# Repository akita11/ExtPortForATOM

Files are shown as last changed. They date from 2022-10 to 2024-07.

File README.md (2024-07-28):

# ExtPortForATOM

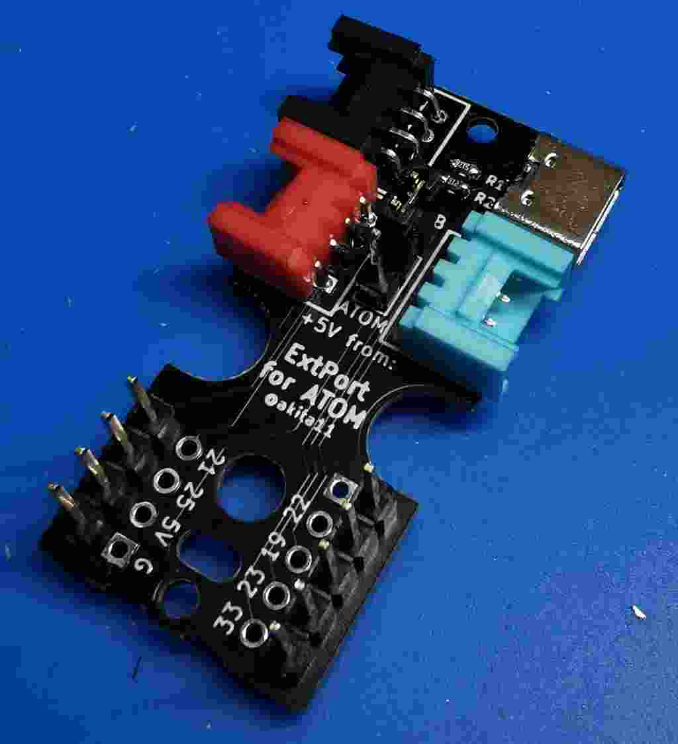
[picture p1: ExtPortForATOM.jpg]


M5stackのATOMシリーズ ([Lite](https://www.switch-science.com/products/6262) / [Matrix](https://www.switch-science.com/products/6260)に3つのGroveポートを拡張します。Groveポートへの給電はATOMから、またはUSB Type-Cコネクタからを選択できます。

※M5Stack純正の[ATOM PortABC](https://www.switch-science.com/products/9198)とピン配置・コネクタの色は同一ですが、Portの名称が異なります(本品=B/C/D、ATOM PortABC=A/B/C)

## 使い方

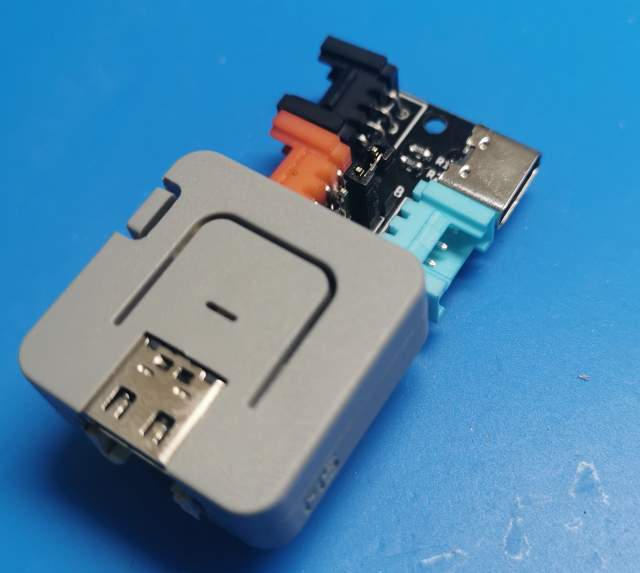
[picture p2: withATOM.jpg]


ATOMを上図のように取り付けて使います。

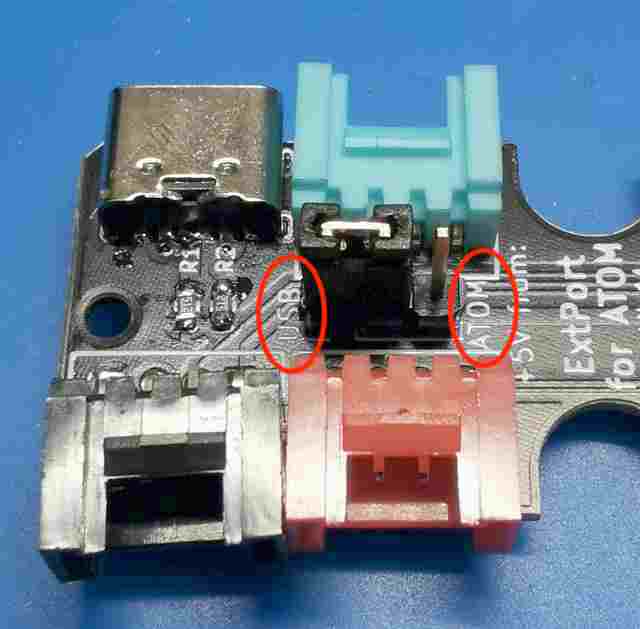
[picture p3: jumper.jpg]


GroveポートのVDD(+5V)への給電は、ボード上のショートピンで切り替えることができます。

- ”ATOM"側 : ATOMの+5V端子から給電（デフォルト）
- ”USB"側 : USB Type-C端子から給電（別途、USB ACアダプタやモバイルバッテリ等から給電してください）

## ピン配置

各ポートはATOMの以下のIOピンに接続されています。UIFlowからも利用可能となる予定です。

- PortB（赤色） : IO21/IO25/VDD/GND
- PortC（黒色） : IO33/IO23/VDD/GND
- PortD（青色） : IO19/IO22/VDD/GND

※ATOM-S3の場合は以下のようになります。

- PortB（赤色） : IO39/IO38/VDD/GND
- PortC（黒色） : IO8/IO7/VDD/GND
- PortD（青色） : IO6/IO5/VDD/GND

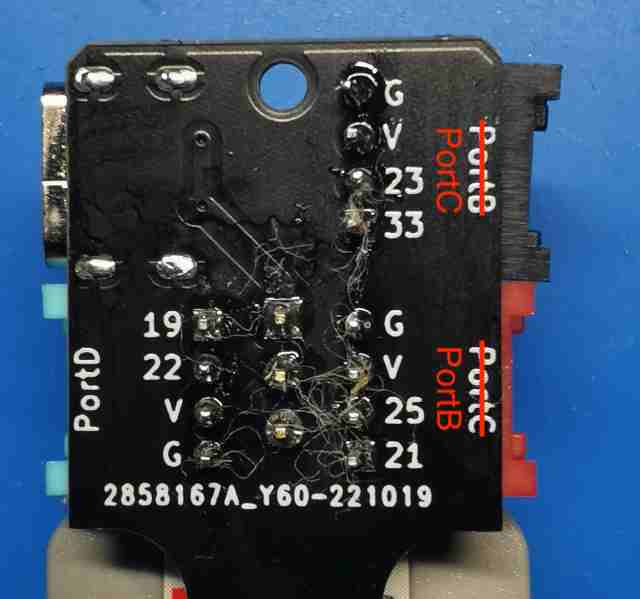
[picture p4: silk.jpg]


※初期ロットでは裏面シルクに間違いがあります。PortBとPortCの表記が逆になっていますのでご注意ください。（コネクタの色で各Portの名称を確認してください）

## Author

Junichi Akita (akita@ifdl.jp, @akita11)

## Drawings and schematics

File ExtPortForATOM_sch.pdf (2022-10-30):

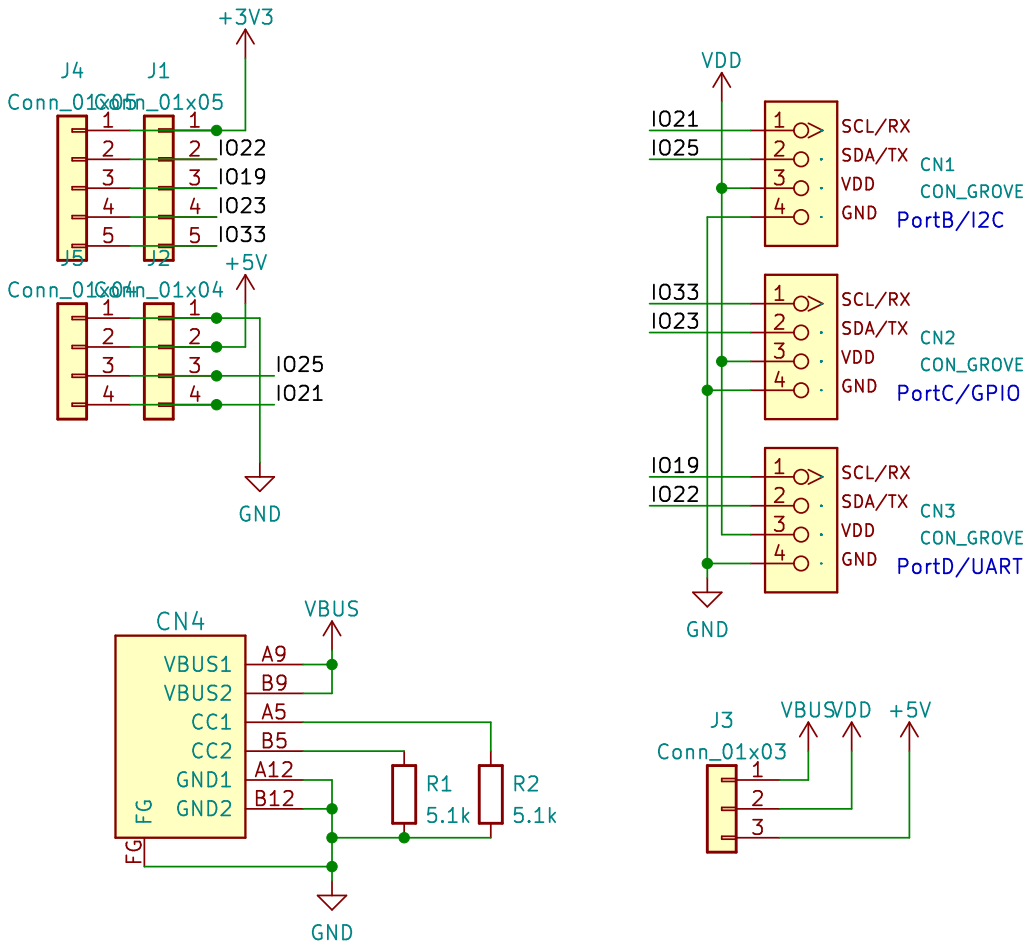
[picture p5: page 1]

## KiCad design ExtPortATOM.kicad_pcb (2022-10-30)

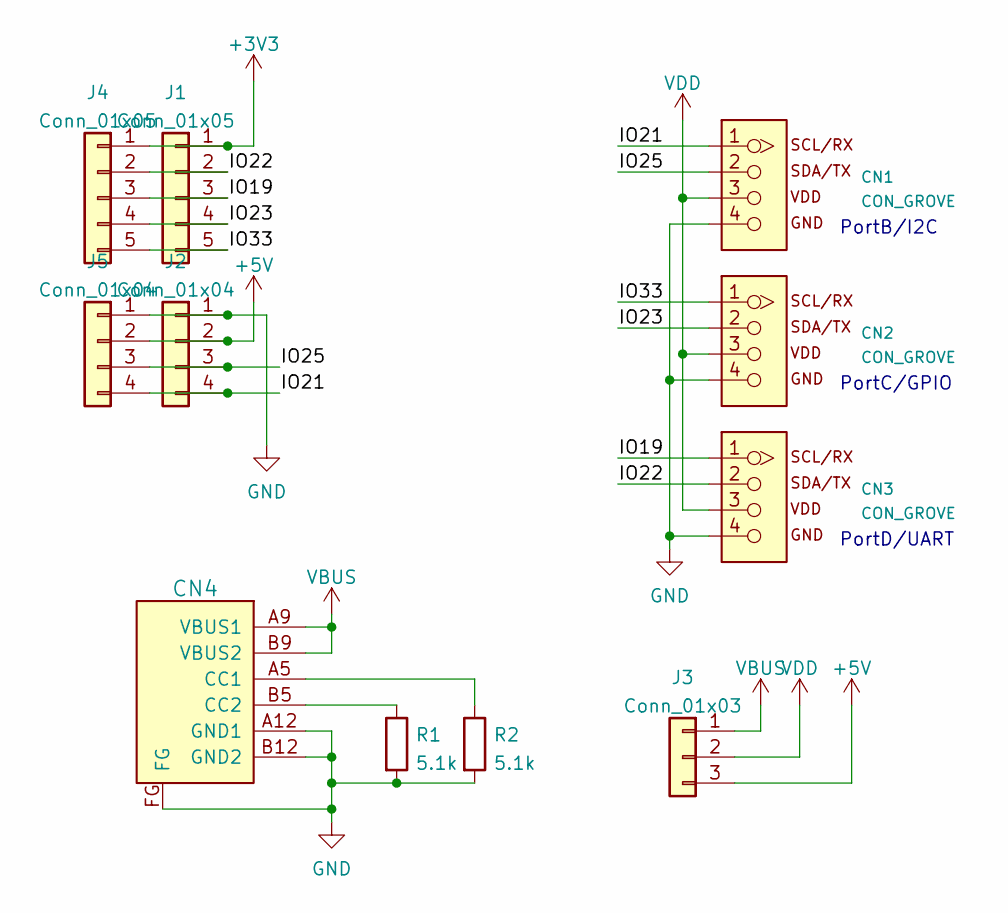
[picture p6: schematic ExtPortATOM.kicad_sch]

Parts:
CN1, CN2, CN3: CON_GROVE; CON_GROVE_H
CN4: CON_USB-C-6; USB-C_6P
J1, J4: Conn_01x05; PinHeader_1x05_P2.54mm_Vertical
J2, J5: Conn_01x04; PinHeader_1x04_P2.54mm_Vertical
J3: Conn_01x03; PinHeader_1x03_P2.54mm_Vertical
R1, R2: 5.1k; R_0603_1608Metric

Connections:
+3V3: J1.1, J4.1
+5V: J2.2, J3.3, J5.2
/IO19: CN3.1, J1.3, J4.3
/IO21: CN1.1, J2.4, J5.4
/IO22: CN3.2, J1.2, J4.2
/IO23: CN2.2, J1.4, J4.4
/IO25: CN1.2, J2.3, J5.3
/IO33: CN2.1, J1.5, J4.5
GND: CN1.4, CN2.4, CN3.4, CN4.A12 (GND1), CN4.B12 (GND2), CN4.FG, J2.1, J5.1, R1.2, R2.2
unnamed: CN4.A5 (CC1), R2.1
unnamed: CN4.B5 (CC2), R1.1
VBUS: CN4.A9 (VBUS1), CN4.B9 (VBUS2), J3.1
VDD: CN1.3, CN2.3, CN3.3, J3.2

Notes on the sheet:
PortD/UART
PortB/I2C
PortC/GPIO

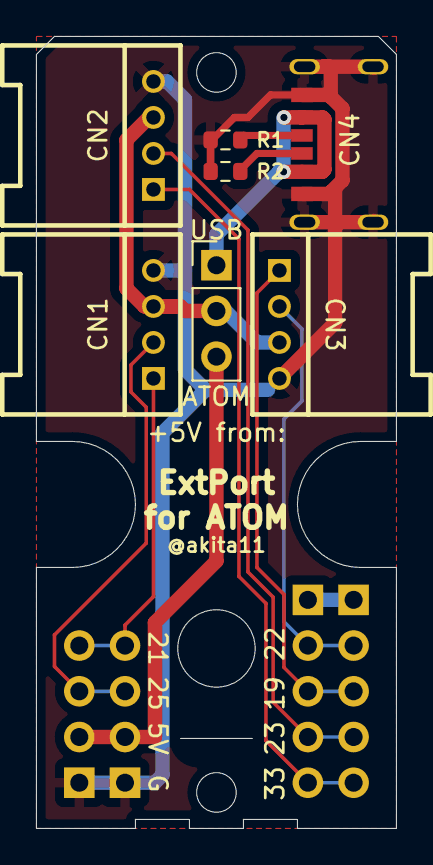
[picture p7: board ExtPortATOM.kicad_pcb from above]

Board: 2 copper layers, 20.0 x 44.0 mm, 11 parts (0 on the bottom side), 13 nets.

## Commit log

2022-10-30 add board data
    [ExtPortATOM.kicad_pcb, ExtPortATOM.kicad_sch]
2024-07-19 pin assign for ATOM-S3
